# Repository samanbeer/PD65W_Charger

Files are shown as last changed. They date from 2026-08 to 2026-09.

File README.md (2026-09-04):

# PD65W Smart Charger 







---

## Project Overview

- **What is it?**  It is a fast 65W charger with Powerdelivery, but its SMART! It has XIAO RP2040 MCU inside and if you want to know more then read more below! 
- **What does it do?**  Belive or not its charging phone :O   Well, it is also charging modern notebooks and all other things, that have USB-C, with a maximum power of 65W which is really good. And WHILE it is charging your device, the RP2040 is with help of INA226 chip measuring input/output Voltage and Current and displaing it on 128x32 display. 
Also the chragers can be really hot while charging, but not this one. Why? Because this one has a FAN! And if the RP2040 starts to measure big temperature on thermistors then it will adjust FAN speed to cool it off.
- **Why does it exist?** Because normal charger from shops are boring, and with this charger you can see how much current and how big voltage is flowing to your phone! But also a good point why does this exist is to **reuse** old adapters from laptops or routers that have 9-24V.

---

## Why I Made This

A few months ago, I bought a small PD65W module on AliExpress to charge my phone and laptop from old 20V laptop adapter. I designed a simple 3D printed enclosure for it (which I also shared on [MakerWorld](https://makerworld.com/en/models/3175390-mini-pd-65w-trigger-charger-8-30v-case#profileId-3590634)). 

But when I connected a 65W power bank, and it was running at max power, the module and adapter was extremely hot! I also taped 10kΩ thermistor on the top of the power source on surface and I measured with multimeter temperatures over 55°C, and the internal heat was melting the PLA enclosure. And yes, I could just print it in PETG or ASA but that would not solve problem for this extreme heat.

That inspired me to build a complete, custom PCB based smart charger that fixes issues of that old setup:

1. **Cooling:** Added a 25x25x6mm 5V fan with holes for intake and exhaust
2. **2 Thermistors:** One thermistor is directly on the PD65W module, and second one is monitoring enclosure temperature
3. **OLED Display:** "0.91" OLED screen displays input voltage, input current, output voltage, output current, total wattage, temperatures, and fan speed **All in real time**.
5. **And lot more**

---

## Project Gallery

### 3D PCB Renders
<p align="center">
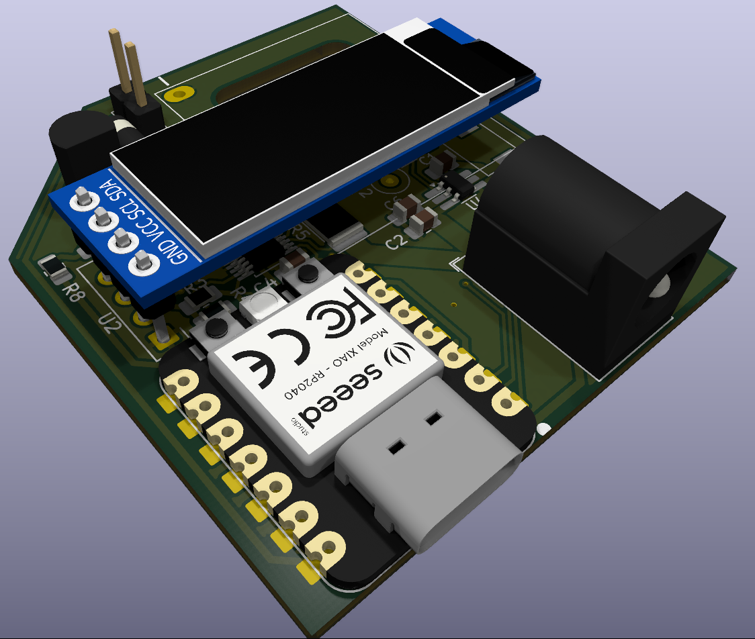
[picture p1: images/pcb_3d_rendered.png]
Rendered PCB Top
  
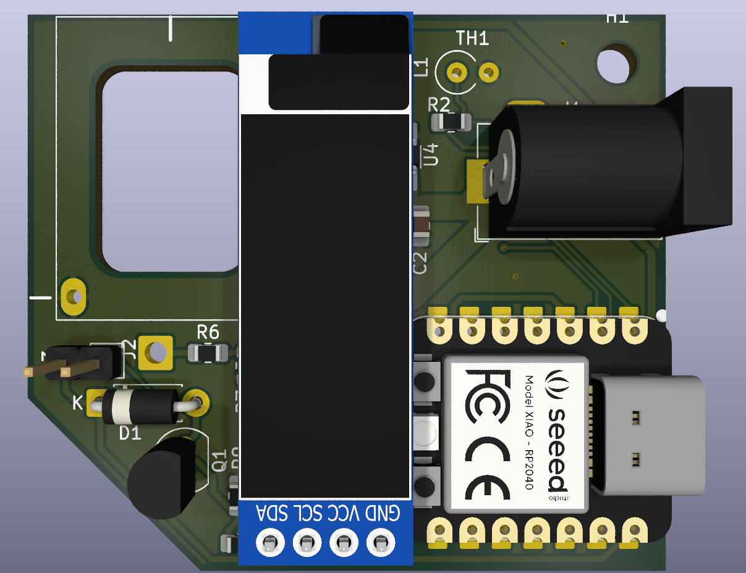
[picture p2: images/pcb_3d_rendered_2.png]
Rendered PCB Angled
  
</p>

### 3D Board Views
<p align="center">
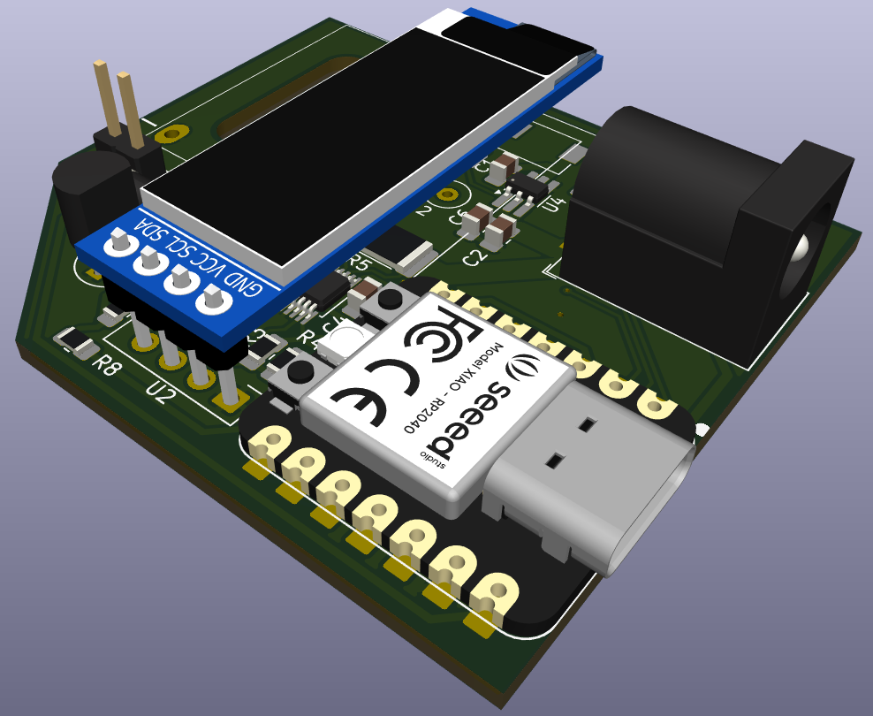
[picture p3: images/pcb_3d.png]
3D PCB Front
  
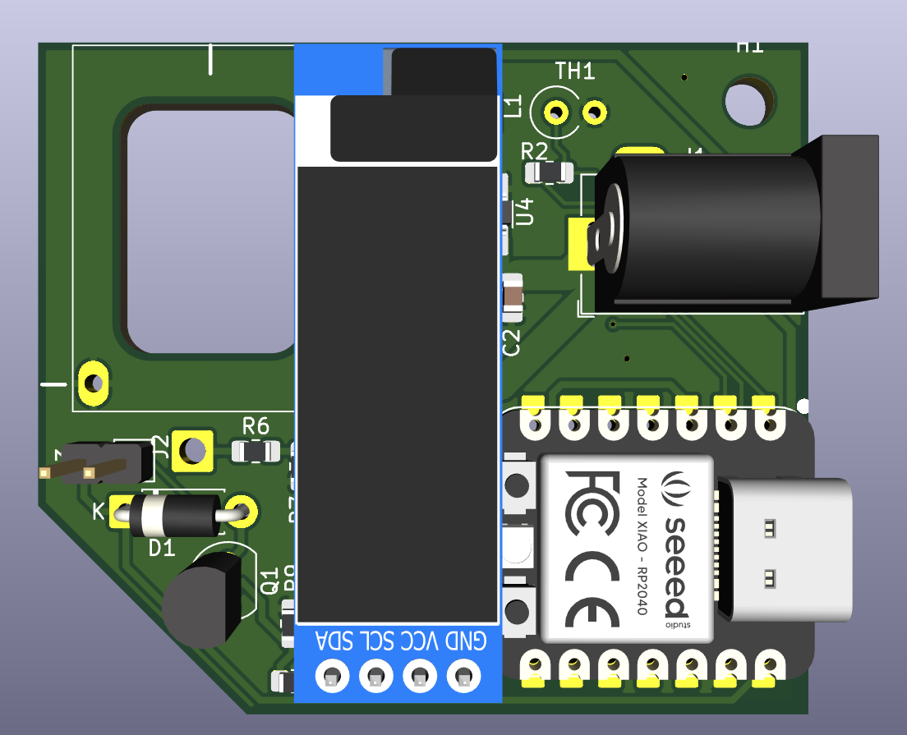
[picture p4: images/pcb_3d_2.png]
3D PCB Back
  
</p>

### PCB Layout & Schematic
<p align="center">
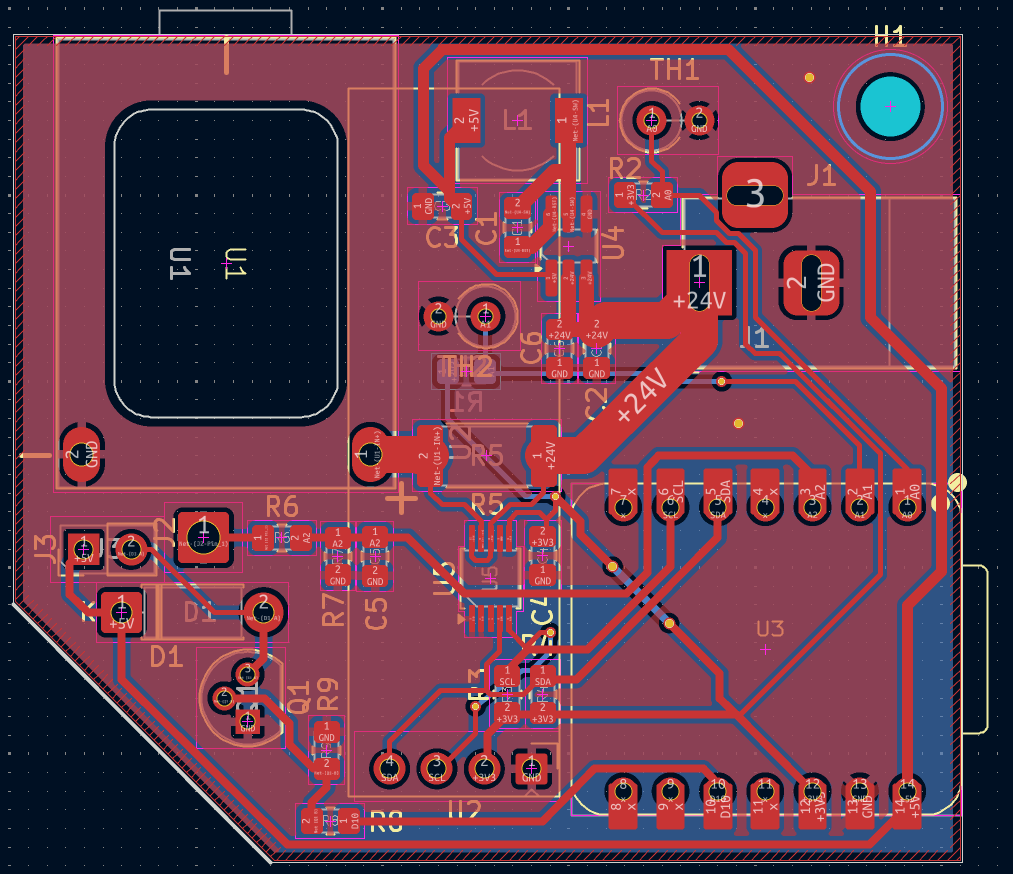
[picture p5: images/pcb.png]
PCB Layout
  
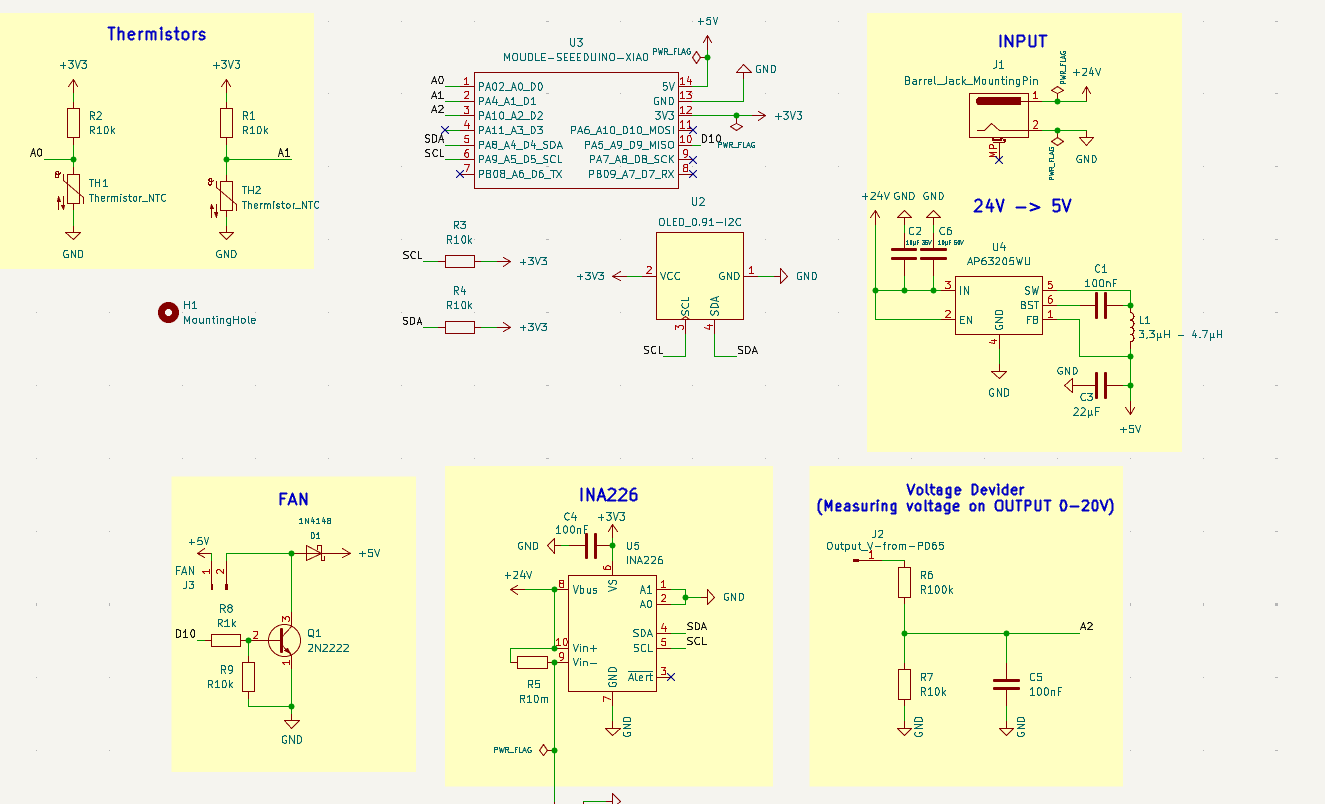
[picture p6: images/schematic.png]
Schematic Diagram
  
</p>

### 3D Enclosure (Fusion 360)
*Custom 3D printable enclosure designed in Fusion 360. All CAD and 3D model files (`.f3z`, `.step`) are located in the [`CAD/`](CAD/) folder.*

<p align="center">
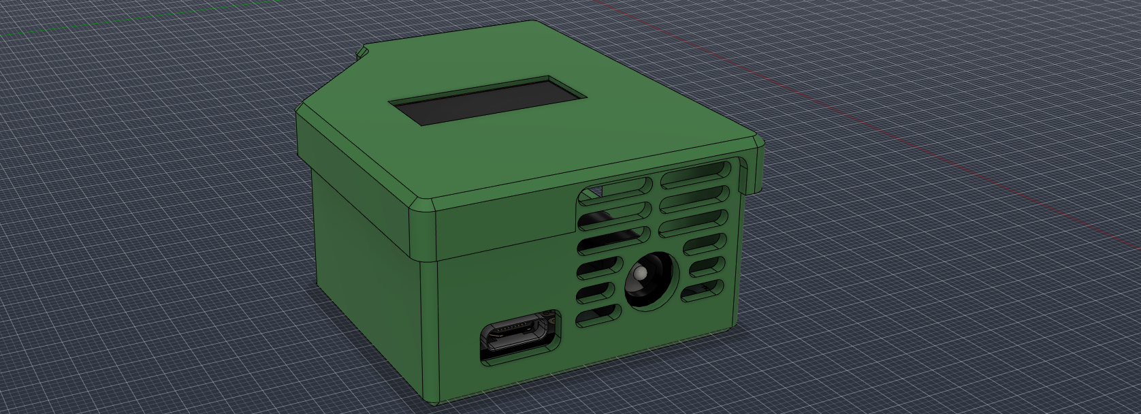
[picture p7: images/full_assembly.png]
Fusion 360 Full Assembly
  
</p>

<p align="center">
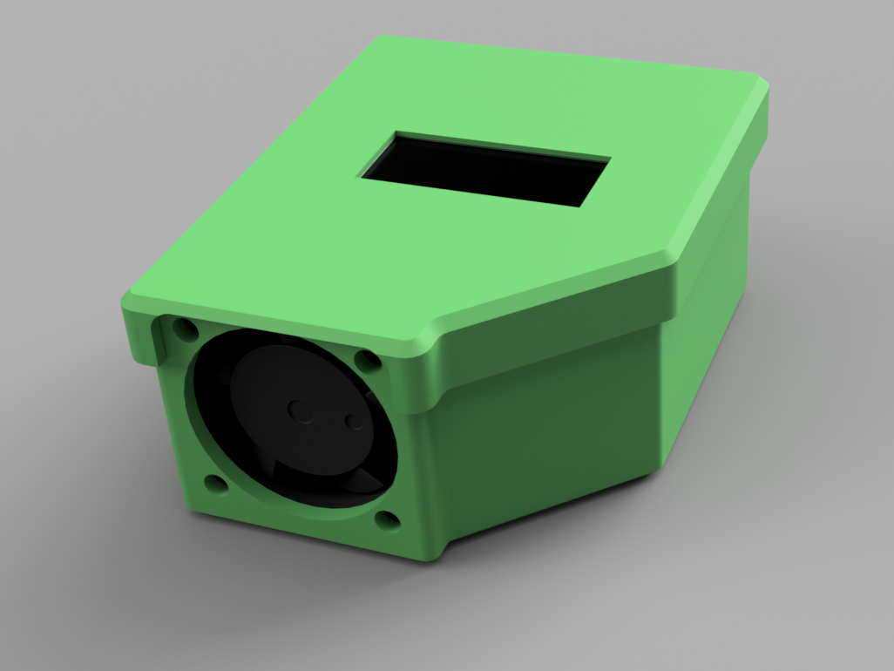
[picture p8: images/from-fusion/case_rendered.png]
Fusion 360 Case Render Front
  
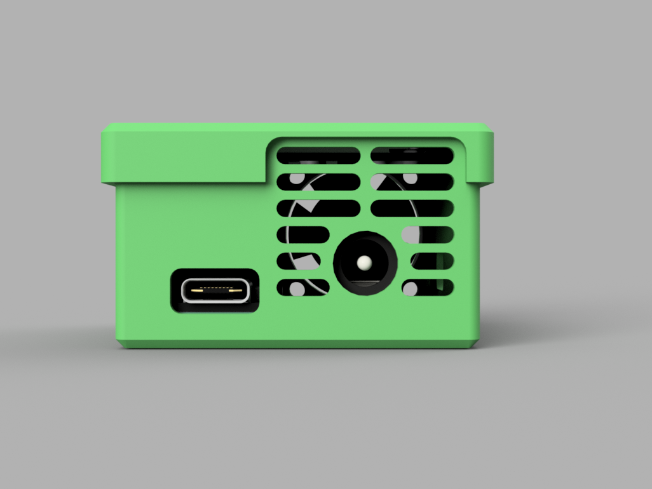
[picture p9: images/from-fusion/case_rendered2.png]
Fusion 360 Case Render Rear
  
</p>

<p align="center">
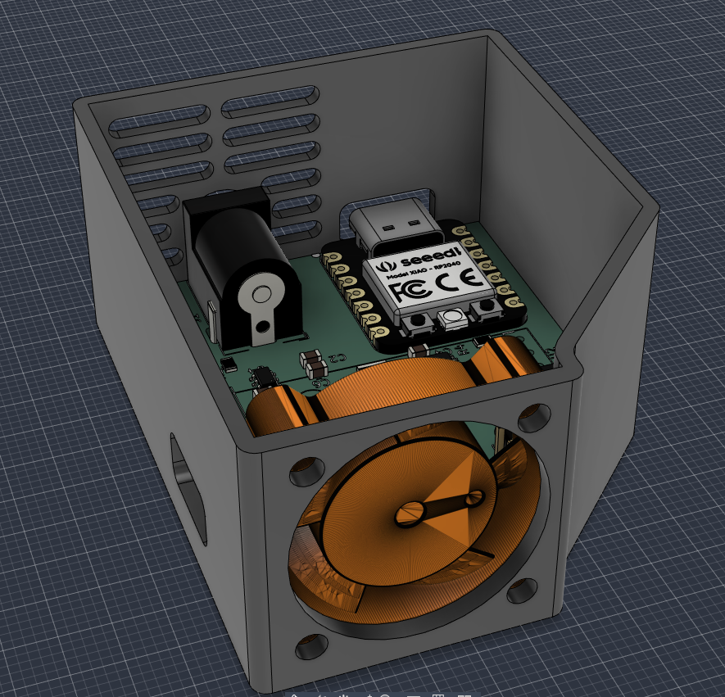
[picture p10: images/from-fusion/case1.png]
Fusion 360 Case Internal Assembly
  
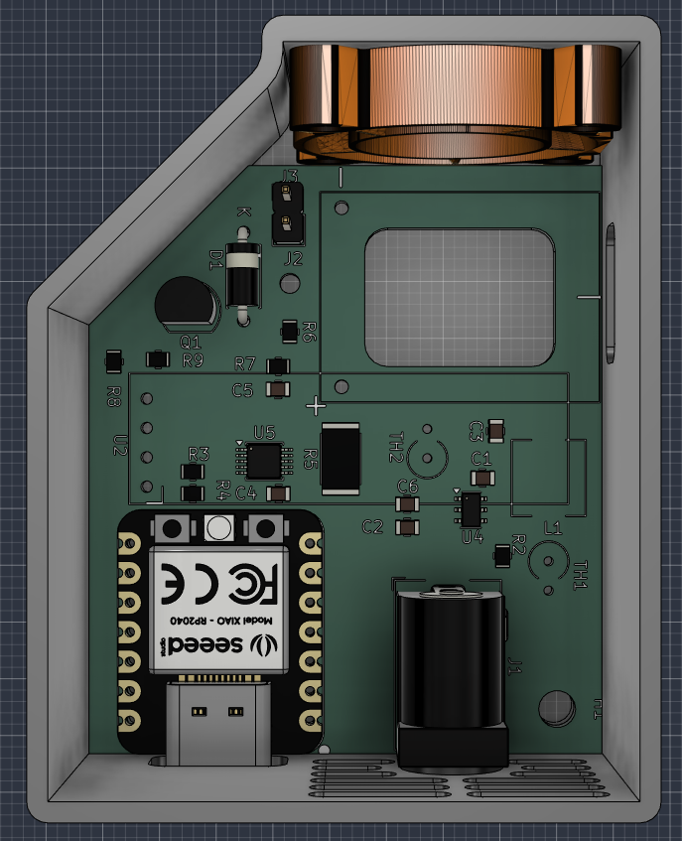
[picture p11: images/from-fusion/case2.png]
Fusion 360 Internal PCB Placement
  
</p>

<p align="center">
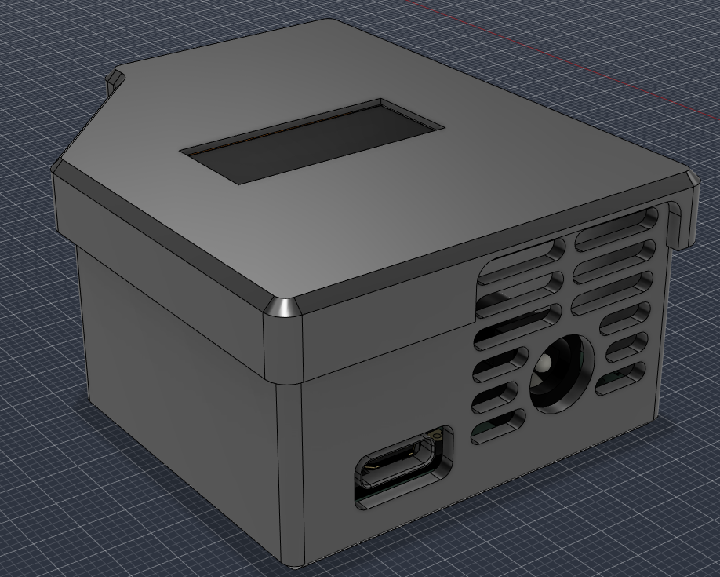
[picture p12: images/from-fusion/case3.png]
Fusion 360 Case Model View
  
</p>

---

### Schematic Blocks:

1. **AP63205 Step-Down Regulator:**
   - Steps down the 9V–24V DC input to a stable, clean **5.0V** (up to 2A) to power the XIAO RP2040, the 0.91" OLED display, and the 5V fan.
   - Uses a 4.7µH high-current power inductor (`L1`) and ceramic filter capacitors (`C2`, `C3`, `C4`).
2. **INA226:**
   - Sits on the primary input DC track through a precision 10mΩ (2512 size) shunt resistor (`R5`).
   - Communicates with the RP2040 over I2C (Address `0x40`), providing millivolt and milliamp precision for input power measurements.
3. **Output Voltage and Power calculation:**
   - A 100kΩ / 10kΩ precision resistor divider (`R6`, `R7`) scales down the 0V–20V USB-PD output rail to a safe 0V–1.82V signal for the RP2040 ADC (`A2`).
   - The firmware combines measured input power with known module conversion efficiency (~92%) and measured output voltage to calculate real time output current and power.
4. **2 Thermistors and Intelligent Fan:**
   - The cooling fan is controlled through a 2N2222 transistor (`Q1`) with a 1N4148 flyback diode (`D1`). If temperatures stay under 35°C, the fan stays completely silent (0% PWM). Between 35°C and 60°C, the fan dynamically scales speed (70–255 PWM). If temperature exceeds 60°C, the fan spins up at full 100% speed.

---

## Assembly Guide

### Required Tools & Materials
- Soldering iron 
- Some good solder wire
- Solder flux 
- Tweezers
- 3D Printer (for printing the Fusion 360 case in PETG, ABS, or PLA)
- Thermal paste or thermal conductive tape (for NTC thermistor contact)

### Assembly Steps

1. **Solder SMD ICs (U4, U5):**
   - Apply flux to the footprint pads of the **AP63205** (U4, TSOT-23-6) and **INA226** (U5, TSSOP-10).
   - Tack one corner pin, align all pins accurately under magnification, and solder the remaining pins.
2. **Solder SMD Passives & Inductor:**
   - Solder the 10mΩ 2512 shunt resistor (`R5`).
   - Solder 0805 SMD resistors (`R1–R4`, `R6–R9`) and capacitors (`C1–C6`).
   - Solder the 4.7µH power inductor (`L1`).
3. **Solder Through-Hole Components:**
   - Solder the 2N2222 transistor (`Q1`), 1N4148 diode (`D1`), and 2-pin Fan pin header (`J3`).
   - Solder the DC Barrel Jack (`J1`). There must be a good contact so put a lot of solder here.
4. **Modules:**
   - Solder the **XIAO RP2040** (`U3`) using female headers or solder direct-to-board as a SMD.
   - Solder the **PD65W Module** (`U1`) and connect the power output feedback wire (`J2`) between the module's positive output terminal and the voltage divider pad.
   - Mount the **0.91" I2C OLED Display** (`U2`) to the I2C header pins.
5. **Thermistors (TH1, TH2):**
   - Solder the thermistor.
   - Fasten `TH1` against the PD65W module power inductor/MOSFETs using thermal tape.
   - Position `TH2` near the board center to monitor ambient enclosure temperature.
6. **Final Case & Fan Assembly:**
   - Mount the 25mm 5V fan into the 3D-printed enclosure exhaust port and plug its 2-pin connector into `J3`.
   - Place the PCB and OLED into the case mounting hole and fasten with some tape.

---

## Firmware & Software Setup

### 1. Required Libraries
Install the following libraries via the Arduino IDE Library Manager:
- `INA226_WE` (by Wolfgang Ewald)
- `Adafruit GFX Library` (by Adafruit)
- `Adafruit SSD1306` (by Adafruit)
- `Wire` (Standard I2C library) - should be included

### 2. Flashing the XIAO RP2040
1. Connect the Seeed XIAO RP2040 to your computer via USB-C while holding down the **`BOOT`** button (or select the board port in Arduino IDE).
2. Select Board: **Seeed Studio XIAO RP2040** 
3. Open [`Firmware/code.ino`](Firmware/code.ino).
4. Click **Upload**.
5. Once uploaded, the OLED will start and will show all tha data.

### 3. OLED Telemetry Display Breakdown

```text
+-----------------------+
| IN :  24.00V  3.20A   |  <-- DC Barrel Jack Input
| OUT:  20.00V  2.95A   |  <-- USB-PD Output to Device
| PWR:  62.4W           |  <-- Total Active Power
| T1:42C T2:36C FAN:45% |  <-- Module Temp, Board Temp, Fan speed
+-----------------------+
```

---

## 📦 Bill of Materials (BOM)

> Sourced from [TME.eu](https://tme.eu), [AliExpress](https://aliexpress.com)

| Reference | Qty | Value / Component | Footprint / Package | Source / Link | Cost (USD) |
| :--- | :---: | :--- | :--- | :--- | :---: |
| **C1, C4, C5** | 3 | 100nF 50V MLCC | 0805 SMD | [TME Link](https://www.tme.eu/cz/details/cc0805krx7r9bb104/kondenzatory-mlcc-smd/yageo/) | $0.65 |
| **C2, C6** | 2 | 10µF 50V MLCC | 0805 SMD | [TME Link](https://www.tme.eu/cz/details/c2012x5r1v106kac/kondenzatory-mlcc-smd/tdk/c2012x5r1v106k125ac/) | $1.10 |
| **C3** | 1 | 22µF 16V MLCC | 0805 SMD | [TME Link](https://www.tme.eu/cz/details/cl21a226kpclrnc/kondenzatory-mlcc-smd/samsung/) | $0.39 |
| **D1** | 1 | 1N4148 Fast Switching Diode | DO-35 / DO-41 THT | [TME Link](https://www.tme.eu/cz/details/1n4148-cdi/univerzalni-diody-tht/cdil/1n4148/) | $0.1 |
| **J1** | 1 | DC Barrel Jack | Horizontal THT Barrel Jack | [TME Link](https://www.tme.eu/cz/details/fcr681465p/konektory-dc/cliff/fc681465p-dc-10lp/) | $2.42 |
| **J3** | 1 | 2-Pin Fan Header (2.54mm) + Sunon 5V Fan | PinHeader 1x02 + 25x25x6mm Fan | [TME Link](https://www.tme.eu/cz/details/mf25060v1-a99-a/ventilatory-dc-5v/sunon/mf25060v1-1000u-a99/) | $7.90 |
| **L1** | 1 | 4.7µH Power Inductor | SMD 6.3x6.3mm (LSXND6060) | [TME Link](https://www.tme.eu/cz/details/lsxnd6060yel4r7nmg/tlumivky/taiyo-yuden/) | $0.50 |
| **Q1** | 1 | 2N2222 NPN Transistor | TO-92 THT | [TME LInk](https://www.tme.eu/cz/details/2n2222a-dio/tranzistory-npn-tht/diotec-semiconductor/2n2222a/) | $0.90 |
| **R1, R2, R3, R4, R7, R9** | 6 | 10kΩ | 0805 SMD | [TME Link](https://www.tme.eu/cz/details/crcw080510k0fkea/rezistory-smd/vishay/) | $0.084 |
| **R5** | 1 | 10mΩ (0.010Ω) 1% Current Shunt | 2512 High-Power SMD | [TME Link](https://www.tme.eu/cz/details/mar251202fr010s/rezistory-smd/wayon/) | $1.98 |
| **R6** | 1 | 100kΩ 1% Resistor | 0805 SMD | [TME Link](https://www.tme.eu/cz/details/rc0805fr-07100k/rezistory-smd/yageo/rc0805fr-07100kl/) | $0.070 |
| **R8** | 1 | 1kΩ 1% Resistor | 0805 SMD | [TME Link](https://www.tme.eu/cz/details/rc0805fr-071k/rezistory-smd/yageo/rc0805fr-071kl/)  | $0.042 |
| **TH1, TH2** | 2 | 10kΩ NTC Thermistors (B=3950) | Radial / Axial THT | [TME Link](https://www.tme.eu/cz/details/b57891m0103j000/merici-termistory-ntc-tht/tdk/) | $1.45 |
| **U1** | 1 | PD65W USB-C PD Step-Down Module | Custom Module Footprint | [AliExpress Link](https://www.aliexpress.com/item/1005012593373561.html) | $6.00 |
| **U2** | 1 | 0.91" I2C Monochrome OLED Display | 4-Pin I2C Module Header | [AliExpress Link](https://www.aliexpress.com/item/1005008918700196.html) | $5.50 |
| **U3** | 1 | Seeed Studio XIAO RP2040 MCU | XIAO DIP-14 Module | [TME Link](https://www.tme.eu/cz/details/seeed-102010428/vyvojove-kity-ostatni/seeed-studio/xiao-rp2040/) | $7.00 |
| **U4** | 1 | AP63205WU 5V 2A Buck Regulator | TSOT-23-6 SMD | [AliExpress Link](https://www.aliexpress.com/item/1005006407229203.html) | $4.00 |
| **U5** | 1 | INA226AIDGSR Power Monitor IC | TSSOP-10 SMD | [TME Link](https://www.tme.eu/cz/details/ina226aidgsr/operacni-zesilovace-smd/texas-instruments/) | $6.00 |
| **PCB** | 1 | 2-Layer Custom FR-4 PCB (1.6mm) | Custom KiCad Design | [JLCPCB](https://jlcpcb.com) | $9.53 |
| **Shipping** | - | Combined Estimated Shipping | - | AliExpress & TME.eu | ~$10.00 |
| **Total** | | | | | **~$65.62** |

>btw you can import every components that is from TME directly to TME cart with this file: [quick_order_TME.csv](PCB/quick_order_TME.csv) 

<p>
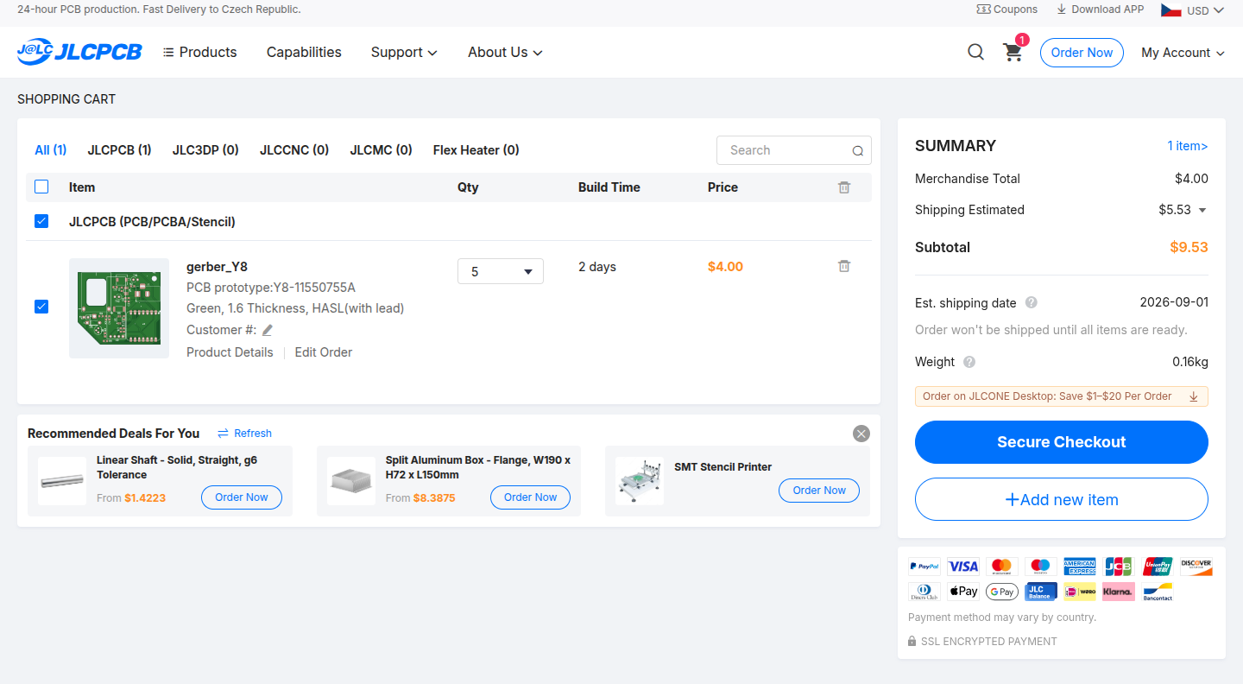
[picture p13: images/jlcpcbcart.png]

</p>

---

## 🚀 How to Use

1. **Connect DC Power:** Plug any 9V to 24V DC power source (almost every old laptop charger) into the rear barrel jack `J1`.
2. **System Initialization:** The OLED display will lights up, showing the measured input voltages and temperatures.
3. **Charge your Device!:** Just connect anything you have with USB-C! (even laptops)
4. **Automatic Cooling:** Under heavy sustained loads (e.g., 45W–65W), the internal fan will automatically spin up smoothly based on thermistor readings, keeping components well within safe operating temperatures.

---

- Designed by **Šámot** in [Hack Club Forge](https://forge.hackclub.com/projects/1660) project.

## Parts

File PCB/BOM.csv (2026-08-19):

Reference | Qty | Value | DNP | Exclude from BOM | Exclude from Board | Footprint
C1,C5 | 2 | 100nF |  |  |  | Capacitor_SMD:C_0805_2012Metric_Pad1.18x1.45mm_HandSolder
C2 | 1 | 10µF 50V |  |  |  | Capacitor_SMD:C_0805_2012Metric_Pad1.18x1.45mm_HandSolder
C3 | 1 | 22µF |  |  |  | Capacitor_SMD:C_0805_2012Metric_Pad1.18x1.45mm_HandSolder
C4 | 1 | 100nF |  |  |  | Capacitor_SMD:C_0805_2012Metric
D1 | 1 | 1N4148 |  |  |  | Diode_THT:D_DO-41_SOD81_P7.62mm_Horizontal
J1 | 1 | Barrel_Jack_MountingPin |  |  |  | Connector_BarrelJack:BarrelJack_GCT_DCJ200-10-A_Horizontal
J2 | 1 | Output_V-from-PD65 |  |  |  | Connector_Wire:SolderWire-1sqmm_1x01_D1.4mm_OD2.7mm
J3 | 1 | FAN |  |  |  | Connector_PinHeader_2.54mm:PinHeader_1x02_P2.54mm_Vertical
L1 | 1 | 3,3µH - 4.7µH |  |  |  | Inductor_SMD:L_Bourns-SRN4018
Q1 | 1 | 2N2222 |  |  |  | Package_TO_SOT_THT:TO-92
R1,R2,R3,R4,R7,R9 | 6 | R10k |  |  |  | Resistor_SMD:R_0805_2012Metric_Pad1.20x1.40mm_HandSolder
R5 | 1 | R10m |  |  |  | Resistor_SMD:R_2512_6332Metric_Pad1.40x3.35mm_HandSolder
R6 | 1 | R100k |  |  |  | Resistor_SMD:R_0805_2012Metric_Pad1.20x1.40mm_HandSolder
R8 | 1 | R1k |  |  |  | Resistor_SMD:R_0805_2012Metric_Pad1.20x1.40mm_HandSolder
TH1,TH2 | 2 | Thermistor_NTC |  |  |  | Resistor_THT:R_Axial_DIN0309_L9.0mm_D3.2mm_P2.54mm_Vertical
U1 | 1 | PD65W_module |  |  |  | Library_footprint:PD65W_module
U2 | 1 | OLED_0.91-I2C |  |  |  | Display:ER_OLEDM0.91_1x-I2C
U3 | 1 | MOUDLE-SEEEDUINO-XIAO |  |  |  | Seeed Studio XIAO Series Library:XIAO-RP2040-DIP
U4 | 1 | AP63205WU |  |  |  | Package_TO_SOT_SMD:TSOT-23-6_HandSoldering
U5 | 1 | INA226 |  |  |  | Package_SO:TSSOP-10_3x3mm_P0.5mm

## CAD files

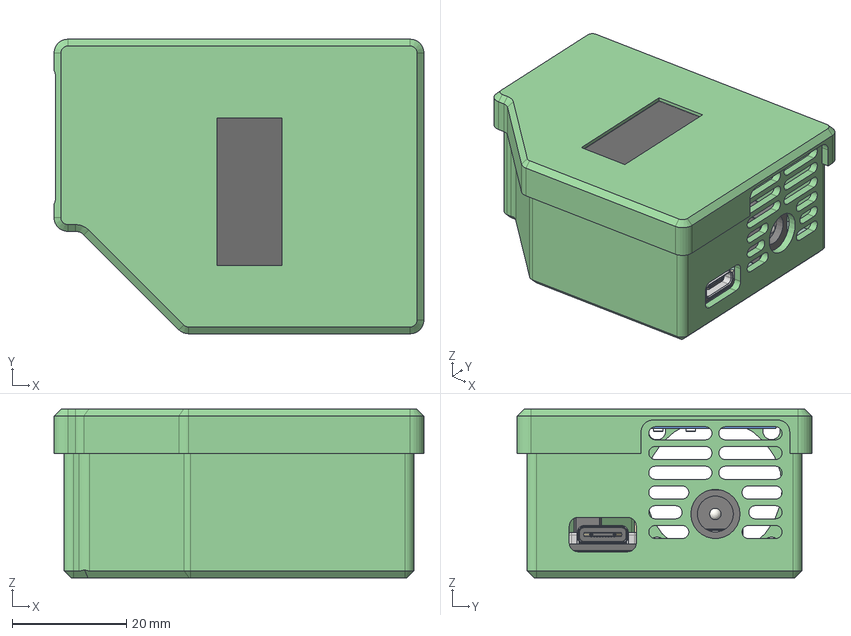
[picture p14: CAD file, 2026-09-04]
CAD/everything_assembled_CASE+PCB.step
64.6 x 51.5 x 29.5 mm
PinHeader_1x02_P254mm_Vertical
R_0805_2012Metric_1 x 8
C_0805_2012Metric_1 x 6
R_2512_6332Metric_1
D_DO-41_SOD81_P7.62mm_Horizontal_1
TSSOP-10_3x3mm_P0.5mm_1
TO-92_Narrow
OLED_0.91_128x32_2
RESC-0603 x 13
2SD0601A
TSOT-23-6_1
BarrelJack_Horizontal_1
type-c v2
smd_button v3
DOUT
DIN
VSS
VDD
smd_button v3(Mirror)
PD65W_Charger_silkscreen
PD65W_Charger_silkscreen_1
PD65W_Charger_PCB

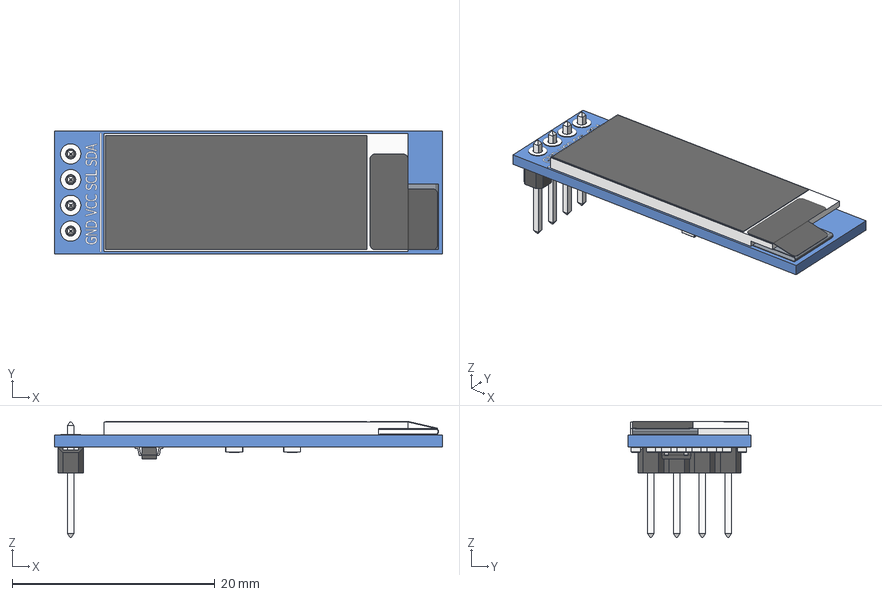
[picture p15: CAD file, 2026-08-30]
PCB/other_libraries/3d_models/OLED_0.91_128x32.stp
38.3 x 12.1 x 11.5 mm
OLED_0.91_128x32
Pin Header 4 x 1 TH 2.54mm Pitch
RESC-0603 x 13
2SD0601A

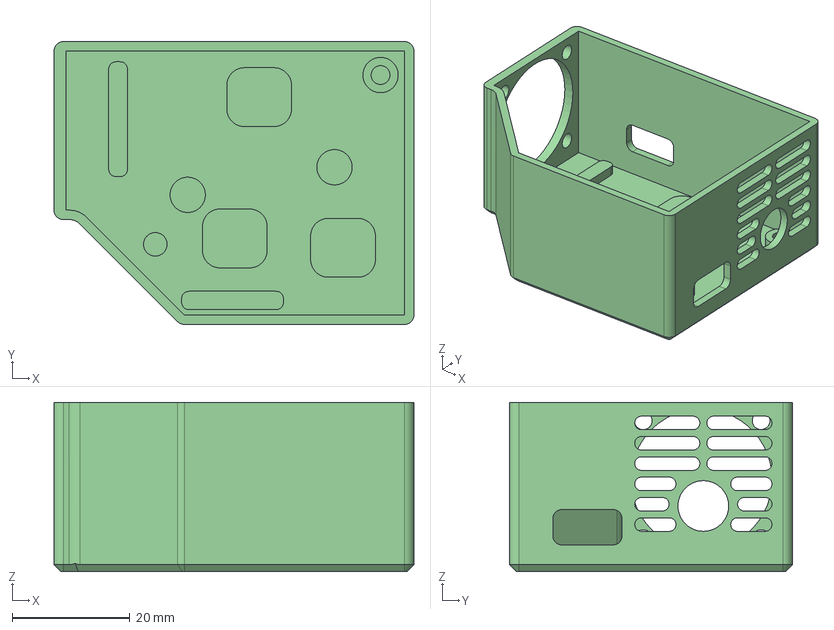
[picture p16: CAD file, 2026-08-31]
CAD/CASE_bottoms.step
61.1 x 48.0 x 28.8 mm

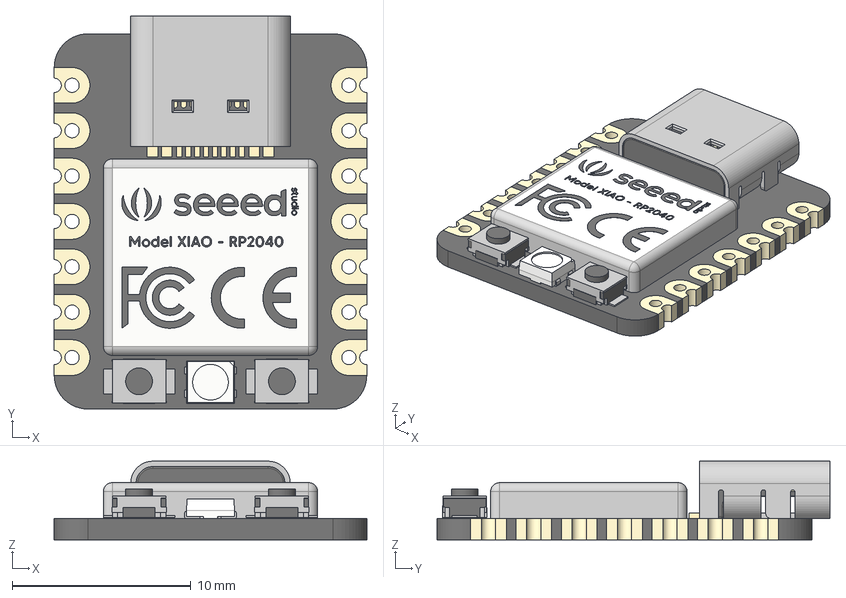
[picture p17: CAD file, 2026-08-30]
PCB/other_libraries/3d_models/Seeed Studio XIAO RP2040 v26.step
17.5 x 22.0 x 4.40 mm
type-c v2
smd_button v3
DOUT
DIN
VSS
VDD
smd_button v3(Mirror)

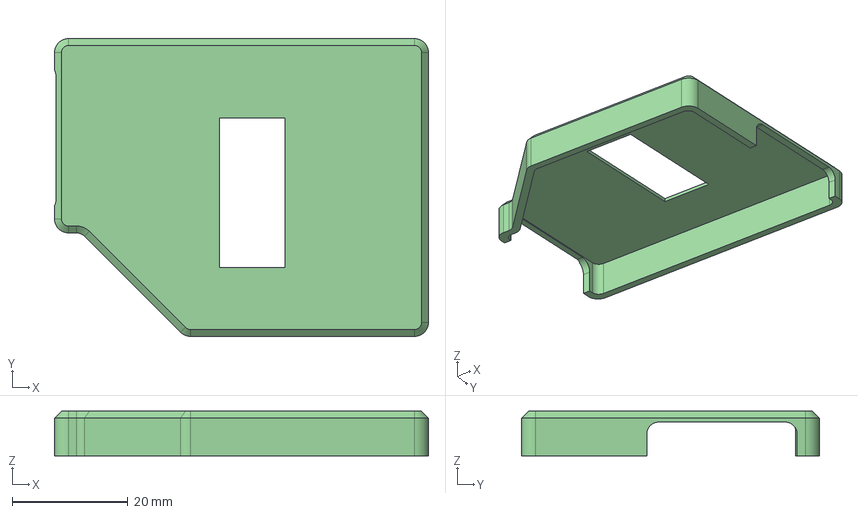
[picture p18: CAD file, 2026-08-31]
CAD/CASE_lid.step
64.6 x 51.5 x 7.74 mm

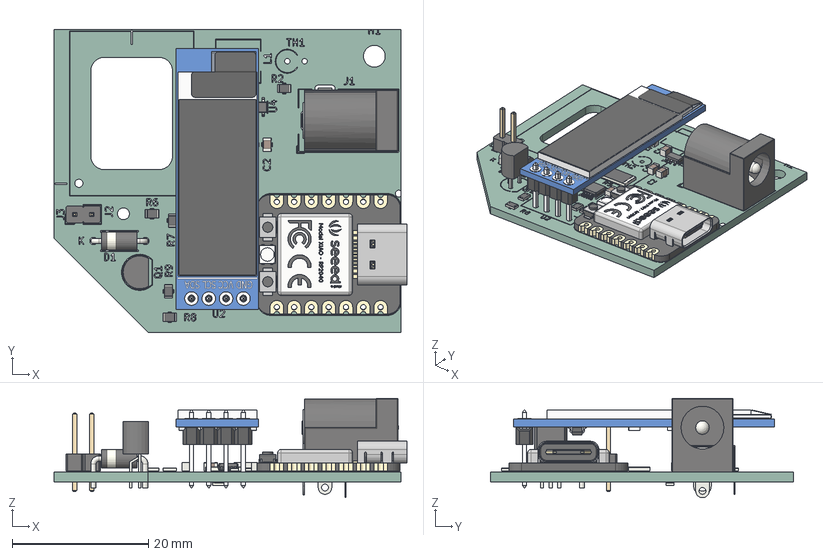
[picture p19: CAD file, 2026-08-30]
CAD/PCB.step
51.8 x 44.4 x 14.6 mm
PinHeader_1x02_P254mm_Vertical
R_0805_2012Metric x 8
C_0805_2012Metric x 6
R_2512_6332Metric
D_DO-41_SOD81_P7.62mm_Horizontal
TSSOP-10_3x3mm_P0.5mm
TO-92_Narrow
OLED_0.91_128x32
Pin Header 4 x 1 TH 2.54mm Pitch
RESC-0603 x 13
2SD0601A
TSOT-23-6
BarrelJack_Horizontal
type-c v2
smd_button v3
DOUT
DIN
VSS
VDD
smd_button v3(Mirror)
PD65W_Charger_silkscreen x 2
PD65W_Charger_PCB

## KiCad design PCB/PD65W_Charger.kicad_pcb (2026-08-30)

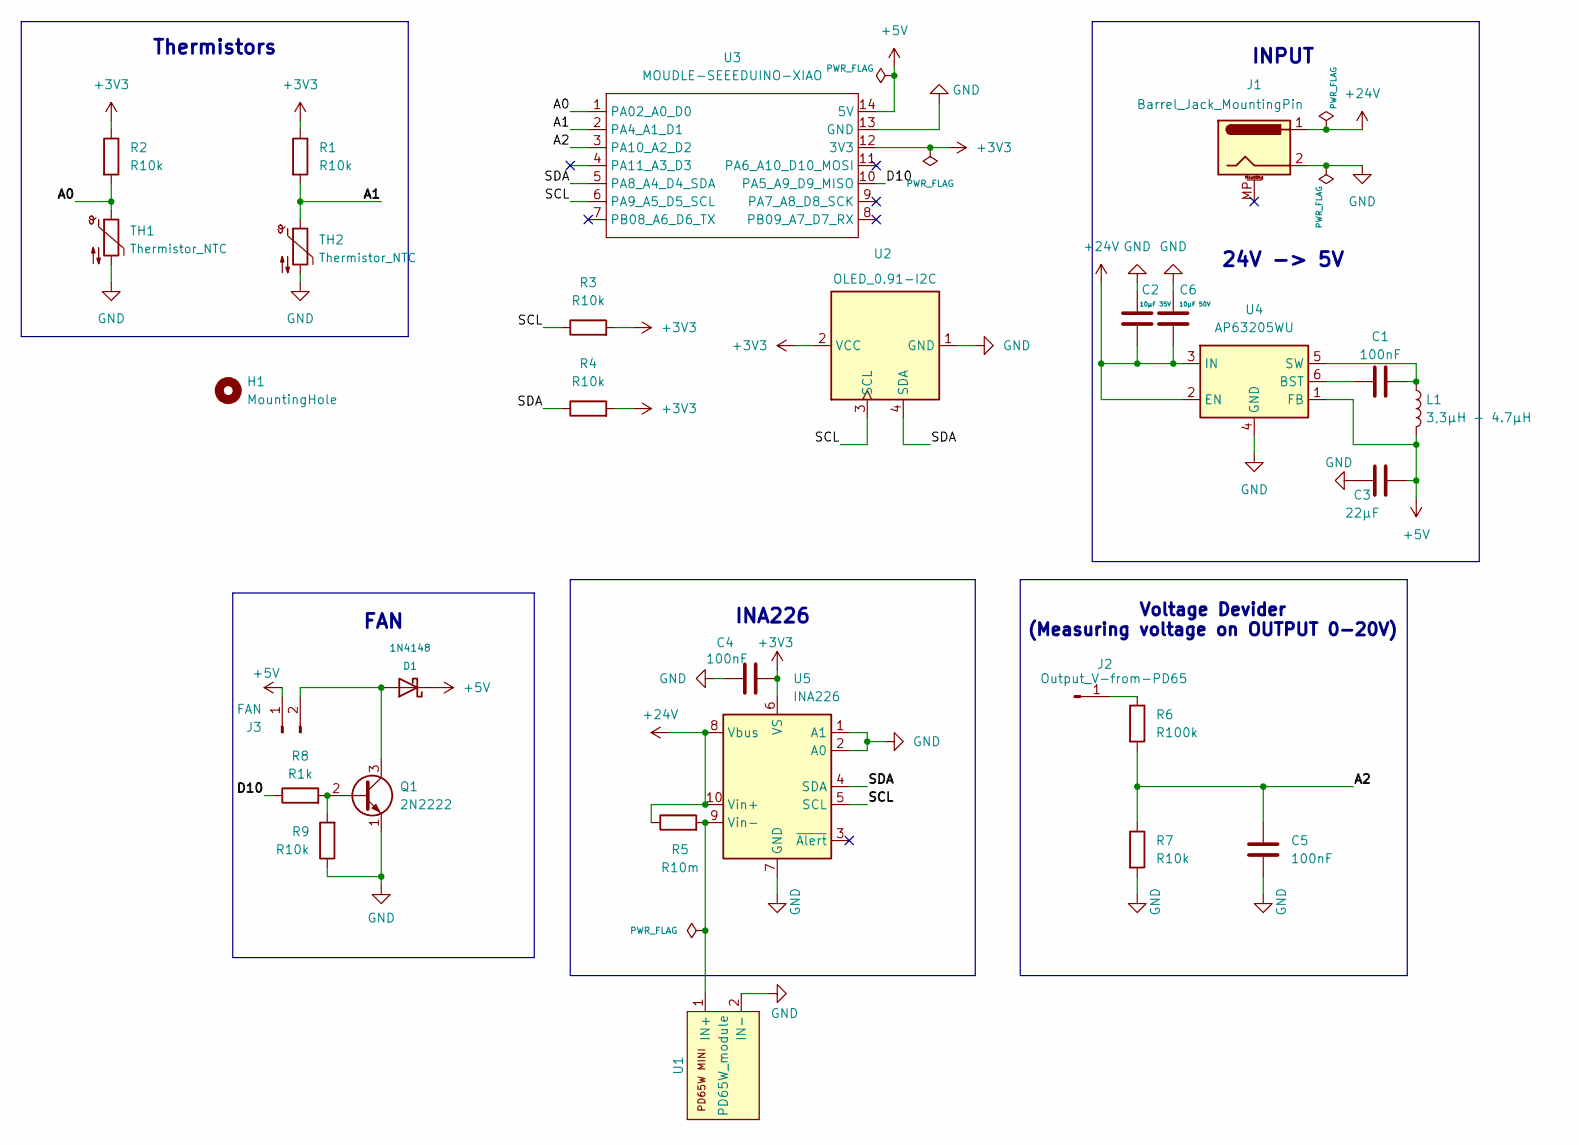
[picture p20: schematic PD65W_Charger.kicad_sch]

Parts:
C1, C4, C5: 100nF; C_0805_2012Metric_Pad1.18x1.45mm_HandSolder
C2: 10µF 35V; C_0805_2012Metric_Pad1.18x1.45mm_HandSolder
C3: 22µF; C_0805_2012Metric_Pad1.18x1.45mm_HandSolder
C6: 10µF 50V; C_0805_2012Metric_Pad1.18x1.45mm_HandSolder
D1: 1N4148; D_DO-41_SOD81_P7.62mm_Horizontal
H1: MountingHole; MountingHole_3.2mm_M3_DIN965
J1: Barrel_Jack_MountingPin; BarrelJack_Horizontal
J2: Output_V-from-PD65; SolderWire-1sqmm_1x01_D1.4mm_OD2.7mm
J3: FAN; PinHeader_1x02_P2.54mm_Vertical
L1: 3,3µH - 4.7µH; L_6.3x6.3_H3
Q1: 2N2222; TO-92
R1, R2, R3, R4, R7, R9: R10k; R_0805_2012Metric_Pad1.20x1.40mm_HandSolder
R5: R10m; R_2512_6332Metric_Pad1.40x3.35mm_HandSolder
R6: R100k; R_0805_2012Metric_Pad1.20x1.40mm_HandSolder
R8: R1k; R_0805_2012Metric_Pad1.20x1.40mm_HandSolder
TH1, TH2: Thermistor_NTC; R_Axial_DIN0309_L9.0mm_D3.2mm_P2.54mm_Vertical
U1: PD65W_module
U2: OLED_0.91-I2C; ER_OLEDM0.91_1x-I2C
U3: MOUDLE-SEEEDUINO-XIAO; XIAO-RP2040-DIP
U4: AP63205WU; TSOT-23-6_HandSoldering
U5: INA226; TSSOP-10_3x3mm_P0.5mm

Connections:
+3V3: C4.2, R1.1, R2.1, R3.2, R4.2, U2.2 (VCC), U3.12 (3V3), U5.6 (VS)
+5V: C3.2, D1.1 (K), J3.1, L1.2, U3.14 (5V), U4.1 (FB)
+24V: C2.2, C6.2, J1.1, R5.1, U4.2 (EN), U4.3 (IN), U5.8 (Vbus), U5.10 (Vin+)
/A0: R2.2, TH1.1, U3.1 (PA02_A0_D0)
/A1: R1.2, TH2.1, U3.2 (PA4_A1_D1)
/A2: C5.1, R6.2, R7.1, U3.3 (PA10_A2_D2)
/D10: R8.1, U3.10 (PA5_A9_D9_MISO)
/SCL: R3.1, U2.3 (SCL), U3.6 (PA9_A5_D5_SCL), U5.5 (SCL)
/SDA: R4.1, U2.4 (SDA), U3.5 (PA8_A4_D4_SDA), U5.4 (SDA)
GND: C2.1, C3.1, C4.1, C5.2, C6.1, J1.2, Q1.1 (E), R7.2, R9.1, TH1.2, TH2.2, U1.2 (IN-), U2.1 (GND), U3.13 (GND), U4.4 (GND), U5.1 (A1), U5.2 (A0), U5.7 (GND)
unnamed: D1.2 (A), J3.2, Q1.3 (C)
unnamed: J2.1 (Pin_1_1), R6.1
unnamed: Q1.2 (B), R8.2, R9.2
unnamed: R5.2, U1.1 (IN+), U5.9 (Vin-)
unnamed: C1.1, U4.6 (BST)
unnamed: C1.2, L1.1, U4.5 (SW)

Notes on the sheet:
INPUT
Voltage Devider (Measuring voltage on OUTPUT 0-20V)
Thermistors
FAN
24V -> 5V
INA226

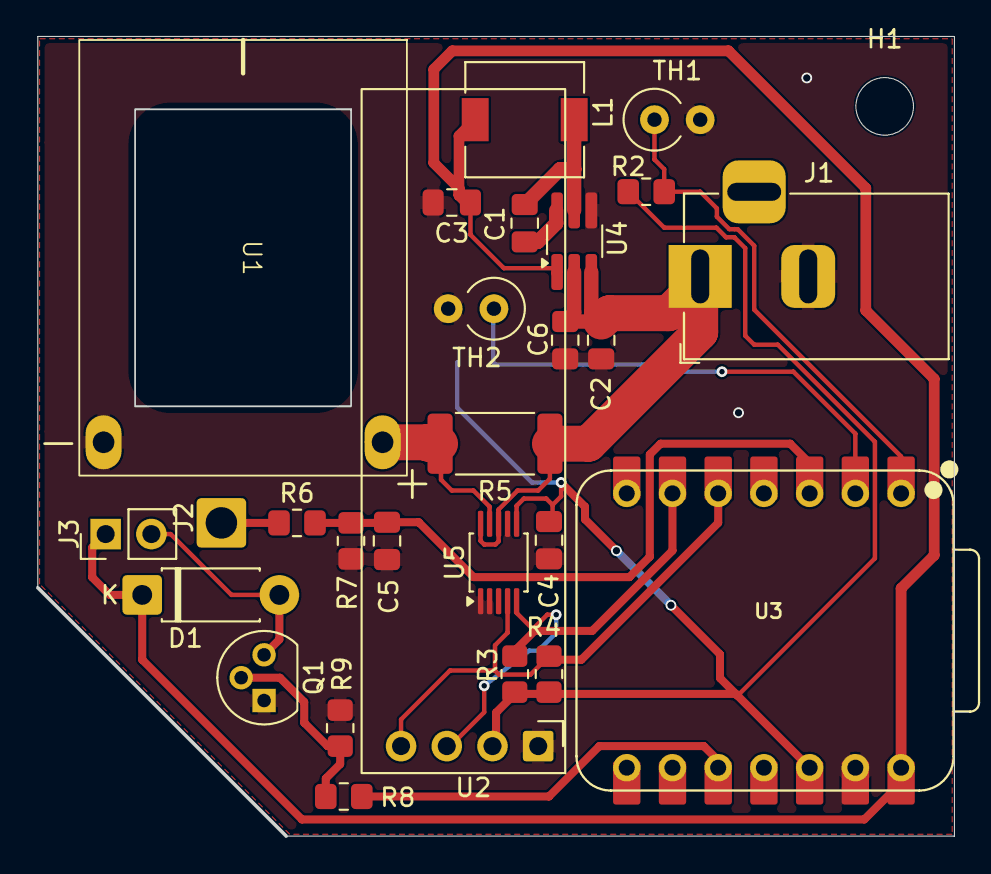
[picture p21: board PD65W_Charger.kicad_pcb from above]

Board: 2 copper layers, 50.9 x 44.4 mm, 29 parts (1 on the bottom side), 16 nets.

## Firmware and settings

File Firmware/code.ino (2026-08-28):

#include <Arduino.h>
#include <math.h>
#include <Wire.h>
#include <INA226_WE.h>
#include <Adafruit_GFX.h>
#include <Adafruit_SSD1306.h>

#define SCREEN_WIDTH        128
#define SCREEN_HEIGHT       64
#define OLED_RESET          -1

#define I2C_DISPLAY_ADDRESS 0x3C //change these if is is not correct for your display
#define I2C_INA_ADDRESS     0x40 //change these if is is not correct for your module

#define NTC1_PIN            A0
#define NTC2_PIN            A1
#define Vout_PIN            A2
#define FAN_PIN             D10

#define R_FIXED             10000.0f
#define NTC_NOMINAL         10000.0f
#define TEMP_NOMINAL        25.0f
#define B_COEFFICIENT       3950.0f
#define ADC_MAX             1023.0f
#define V_REF               3.3f

#define DIVIDER_R1          100000.0f // 100k
#define DIVIDER_R2          10000.0f  // 10k

#define SHUNT_RESISTANCE    0.010f    // 10mOhm (R5)
#define SHUNT_MAX_CURRENT   5.0f      // Max 5A

#define TEMP_FAN_OFF        35
#define TEMP_FAN_MAX        60

#define SENSOR_INTERVAL_MS  100
#define DISPLAY_INTERVAL_MS 250
#define EFFICIENCY_FACTOR   0.92f // module Efficiency 

int fan_speed_pwm;

INA226_WE ina226(I2C_INA_ADDRESS);
Adafruit_SSD1306 display(SCREEN_WIDTH, SCREEN_HEIGHT, &Wire, OLED_RESET);

int temp_1;
int temp_2;

int input_voltage;
int output_voltage;
int input_amp;
int output_amp;

unsigned long last_sensor_time = 0;
unsigned long last_display_time = 0;

void measure_temperatures();
void measure_output_voltage();
void measure_ina226();
void calculate_output_current();
void control_fan();
void update_display();

void setup() {
  analogReadResolution(10);
  pinMode(FAN_PIN, OUTPUT);
  analogWrite(FAN_PIN, 0);

  Wire.begin();
  ina226.init();
  ina226.setResistorRange(SHUNT_RESISTANCE, SHUNT_MAX_CURRENT);

  display.begin(SSD1306_SWITCHCAPVCC, I2C_DISPLAY_ADDRESS);
  display.clearDisplay();
  display.setTextColor(SSD1306_WHITE);
}

void loop() {
  unsigned long current_time = millis();

  if (current_time - last_sensor_time >= SENSOR_INTERVAL_MS) {
    last_sensor_time = current_time;
    measure_temperatures();
    measure_output_voltage();
    measure_ina226();
    calculate_output_current();
    control_fan();
  }

  if (current_time - last_display_time >= DISPLAY_INTERVAL_MS) {
    last_display_time = current_time;
    update_display();
  }
}

void measure_temperatures() {
  const auto calculate_temp = [](int pin) -> int {
    int raw = analogRead(pin);
    if (raw <= 0 || raw >= (int)ADC_MAX) return 0;
    
    float resistance = R_FIXED * (ADC_MAX / (float)raw - 1.0f);
    float steinhart = log(resistance / NTC_NOMINAL) / B_COEFFICIENT + 1.0f / (TEMP_NOMINAL + 273.15f);
    return (int)(1.0f / steinhart - 273.15f);
  };

  temp_1 = calculate_temp(NTC1_PIN);
  temp_2 = calculate_temp(NTC2_PIN);
}

void measure_output_voltage() {
  int raw = analogRead(Vout_PIN);
  float v_adc = (raw / ADC_MAX) * V_REF;
  output_voltage = (int)(v_adc * ((DIVIDER_R1 + DIVIDER_R2) / DIVIDER_R2) * 1000.0f);
}

void measure_ina226() {
  input_voltage = (int)(ina226.getBusVoltage_V() * 1000.0f);
  input_amp = (int)ina226.getCurrent_mA();
}

void calculate_output_current() {
  if (output_voltage > 1000) {
    float pin_mw = (float)input_voltage * (float)input_amp;
    float pout_mw = pin_mw * EFFICIENCY_FACTOR;
    output_amp = (int)(pout_mw / (float)output_voltage);
  } else {
    output_amp = 0;
  }
}

void control_fan() {
  int max_temp = max(temp_1, temp_2); //takes the higher temperature from the two thermistors so it is controled by the hottest one

  if (max_temp < TEMP_FAN_OFF) {
    fan_speed_pwm = 0; //if temperature is below TEMP_FAN_OFF (35°C) the fan is off
  } else if (max_temp >= TEMP_FAN_MAX) {
    fan_speed_pwm = 255; // ir if the temperature is more then TEMP_FAN_MAX (60°C) the fan is at maximum speed
  } else {
    fan_speed_pwm = map(max_temp, TEMP_FAN_OFF, TEMP_FAN_MAX, 70, 255); //if the temprature is between TEMP_FAN_OFF and TEMP_FAN_MAX the fan speed is base on current temperature
  }

  analogWrite(FAN_PIN, fan_speed_pwm);
}

void update_display() {
  display.clearDisplay();
  display.setTextSize(1);

  display.setCursor(0, 0);
  display.print("IN : ");
  display.print(input_voltage / 1000.0f, 2); // measured voltage and amps previosly were in mV and mA, so it need to be divided by 1000 
  display.print("V ");
  display.print(input_amp / 1000.0f, 2);
  display.print("A");

  display.setCursor(0, 16);
  display.print("OUT: ");
  display.print(output_voltage / 1000.0f, 2);
  display.print("V ");
  display.print(output_amp / 1000.0f, 2);
  display.print("A");

  display.setCursor(0, 32);
  display.print("PWR: ");
  display.print((input_voltage / 1000.0f) * (input_amp / 1000.0f), 1); // V*A = W
  display.print("W");

  display.setCursor(0, 48);
  display.print("T1:");
  display.print(temp_1);
  display.print("C T2:");
  display.print(temp_2);
  display.print("C FAN:");
  display.print(map(fan_speed_pwm, 0, 255, 0, 100));
  display.print("%");

  display.display();
}

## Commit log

2026-08-19 Created README.md with BOM
    [BOM.csv, PD65W_Charger.kicad_pcb, PD65W_Charger.kicad_sch]
2026-08-19 Added order_35321745.csv that can be imported to TME.eu that will automatically import all product to cart
    [PD65W_Charger.kicad_pcb, order_35321745.csv]
2026-08-20 update to BOM
    [order_35321745.csv]
2026-08-28 firmware update with temperature measuring, INA226 working, and Vout divider calculating
    [PD65W_Charger.kicad_pcb]
2026-08-30 Everything exccept Documentation done
    [OLED_0.91_128x32.stp, PCB.step, PD65W_Charger.kicad_pcb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]
2026-08-30 everything done except images from fusiion
    [PD65W_Charger-B_Cu.gbr, PD65W_Charger-B_Mask.gbr, PD65W_Charger-B_Paste.gbr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]
2026-08-30 just a clean up
    [PD65W_Charger.kicad_sch]
2026-08-31 added case models, fusion files and images from fusion
    [CASE_bottoms.step, CASE_lid.step]
2026-09-04 Add LICENSE, .gitignore, and include full assembly render in README

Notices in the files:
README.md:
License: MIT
